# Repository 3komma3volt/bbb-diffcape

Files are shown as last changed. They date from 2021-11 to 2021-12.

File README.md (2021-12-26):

# bbb-diffcape

A simple Beaglebone black cape for controlling LED pixels with differential signals

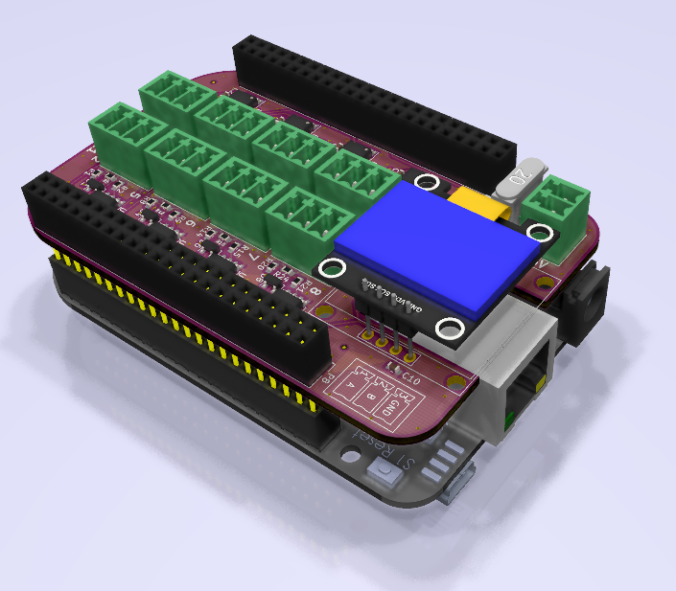
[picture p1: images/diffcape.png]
bbbdiffcape


# Usage
It consists of a simple cape with 8 diffential (RS422) outputs to control pixel strings (e.g. with WS2812B LEDs) over long distances. 
The project includes a receiver board to generate single-ended data for the pixels
It is compatible with [FPP Falcon Player](https://github.com/FalconChristmas/fpp) 
The manufacturing files include LCSC component numbers for direct ordering at [JLCPCB](https://jlcpcb.com)
Only the direct-solder fuse, the headers and the screw terminals have to be soldered manually, if ordered at JLCPCB.

> The boards have very simple designs. 2 layer, no impedance matching, only a bit ESD protection, no supply protection!

## Sending Cape

The folder **bbb-diffcape** contains the [KICAD](https://www.kicad.org) schematic, board and Gerber files. 

> Be aware that the Gerbers and board file are not consistent! In the  Gerbers, the screw terminals are a bit too narrow to each other. It works, but the plugged in connectors have to be bend a bit. The KICAD board is already corrected in R2.

 -  A 0.96" I2C OLED TFT can be mounted, which is supported by FPP to get some status information.
 - 5V connector supplies the Beaglebone and the Diffcape
 - Copy the BBB-Diff.json to the */opt/fpp/capes/bbb/strings* folder for correct configuration within FPP

# bbb-diffcape

A simple Beaglebone black cape for controlling LED pixels with differential signals

bbbdiffcape

# Usage
It consists of a simple cape with 8 diffential (RS422) outputs to control pixel strings (e.g. with WS2812B LEDs) over long distances. 
The project includes a receiver board to generate single-ended data for the pixels
It is compatible with [FPP Falcon Player](https://github.com/FalconChristmas/fpp) 
The manufacturing files include LCSC component numbers for direct ordering at [JLCPCB](https://jlcpcb.com)
Only the direct-solder fuse, the headers and the screw terminals have to be soldered manually, if ordered at JLCPCB.

> The boards have very simple designs. 2 layer, no impedance matching, only a bit ESD protection, no supply protection!

## Sending Cape

The folder **bbb-diffcape** contains the [KICAD](https://www.kicad.org) schematic, board and Gerber files. 

> Be aware that the Gerbers and board file are not consistent! In the  Gerbers, the screw terminals are a bit too narrow to each other. It works, but the plugged in connectors have to be bend a bit. The KICAD board is already corrected in R2.

 -  A 0.96" I2C OLED TFT can be mounted, which is supported by FPP to get some status information.
 - 5V connector supplies the Beaglebone and the Diffcape
 - Copy the BBB-Diff.json to the */opt/fpp/capes/bbb/strings* folder for correct configuration within FPP

> This board is tested and fully functional on all channels!

## Receiver

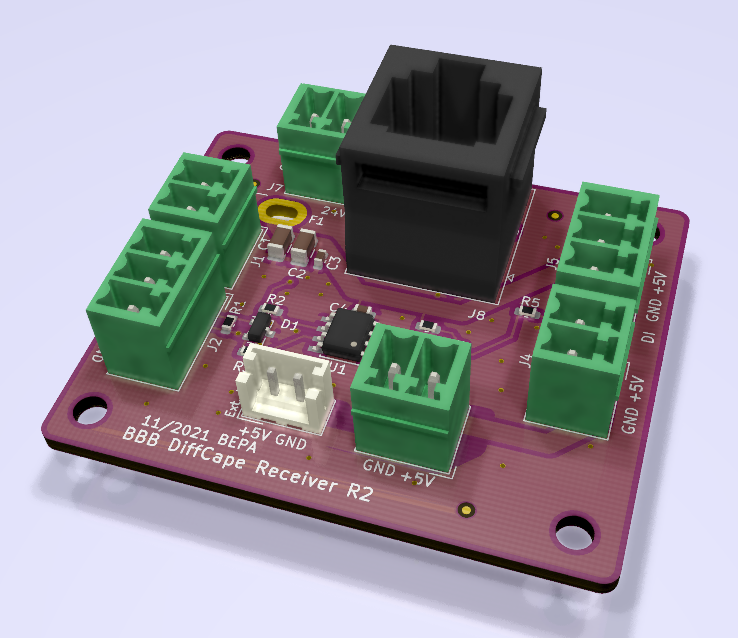
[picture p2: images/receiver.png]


The receiver is designed to support two supply variants

 - Supply with 5V: Just connect power and data as in the picture and the pixel string
 - Supply with 24V via RJ45: For easier cableing, a RJ45 connector for data and power. So there has to be a 24V power supply on the transmission side which powers the system. On the receiver side, a DC/DC converter is needed to power down to 5V. 
 - Excellent for per-prop-use. So one receiver per prop can be used with simple RJ45 cabelling (22AWG) with ~25W supply @ 10m without a big voltage drop
 - Folder "mechanical" contains a FreeCAD file for a simple hotglue mount
 
Because there is no voltage regulator, the receiver is not suited for use with 12V pixels without modifications!

> This board is tested and fully functional!

## ReceiverTransmitter

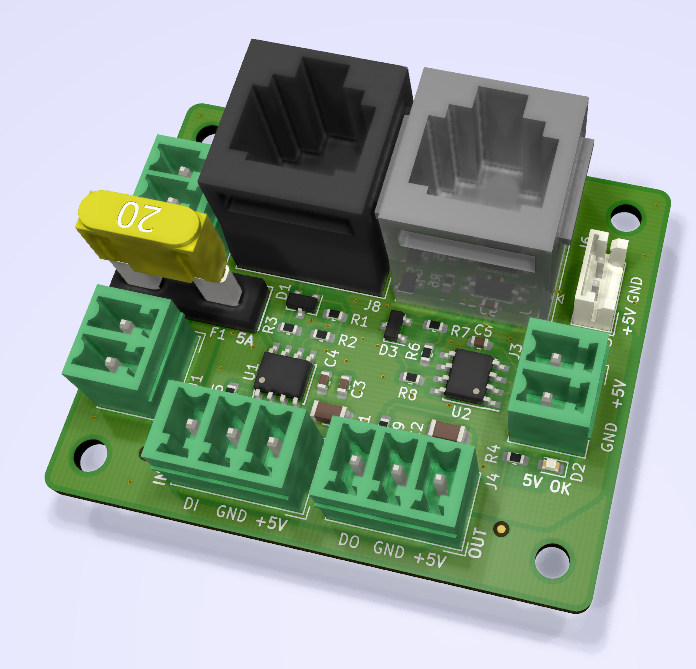
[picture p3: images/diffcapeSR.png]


Receiver with integrated transmitter. With this PCB, you can go back from the last pixel's output to the board and regenerate differential data. It also forwards the 24V power via the RJ45 connector.

> This board is tested and fully functional!

## Distributor

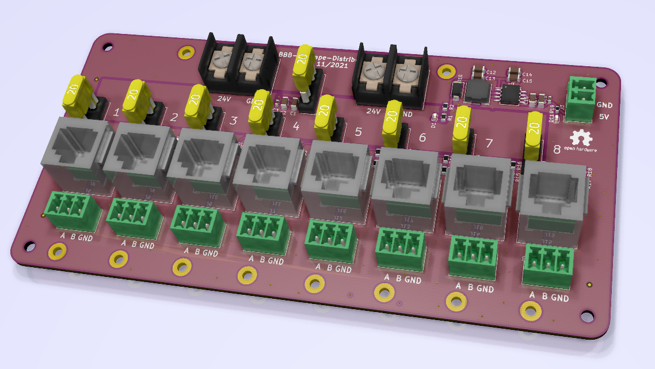
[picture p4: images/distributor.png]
bbbdistributor


With the distributor power and data can be transfered with standard patch cords. A 3A 5V DC/DC converter is used to supply the beaglebone black

> This board is untested!

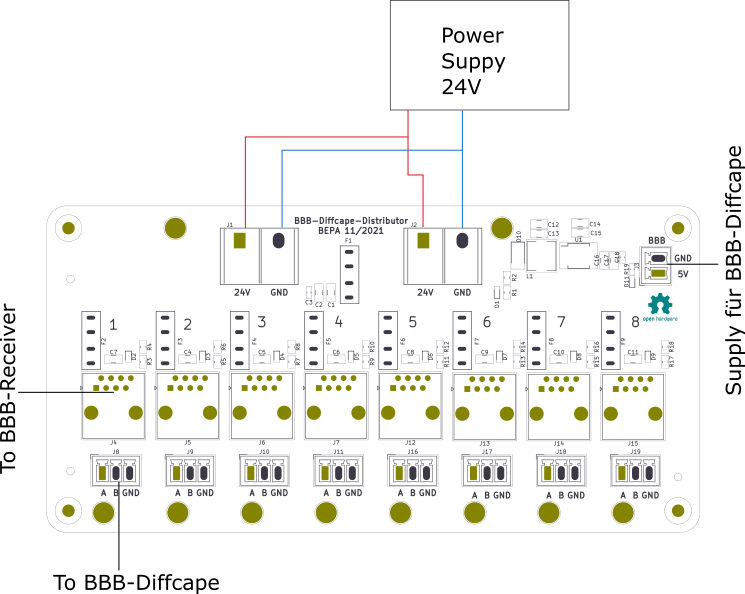
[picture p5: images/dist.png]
bbbdistributorconn


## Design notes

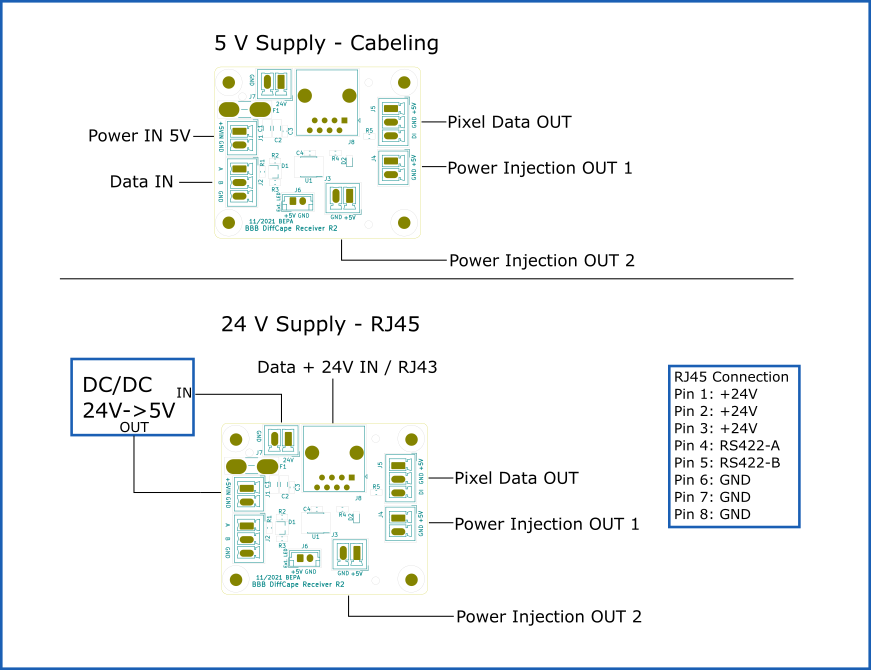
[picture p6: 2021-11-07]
images/bbb-diffcape-receiver-brd.png

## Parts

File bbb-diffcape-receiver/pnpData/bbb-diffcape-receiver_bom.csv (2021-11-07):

Comment | Designator | Footprint | LCSC
100u | C1,C2 | Capacitor_SMD:C_1206_3216Metric | C15008
100n | C3,C4 | Capacitor_SMD:C_0603_1608Metric | C14663
PSM712 | D1 | Package_TO_SOT_SMD:SOT-23 | C32677
LED | D2 | LED_SMD:LED_0603_1608Metric | C72038
5A | F1 | Fuse:Fuse_Blade_Mini_directSolder
Fiducial | FID1,FID2,FID3 | Fiducial:Fiducial_0.75mm_Mask1.5mm
MountingHole | H1,H2,H3,H4 | MountingHole:MountingHole_3.2mm_M3
Screw_Terminal_01x03 | J2,J5 | Connector_Phoenix_MC:PhoenixContact_MCV_1,5_3-G-3.5_1x03_P3.50mm_Vertical
Screw_Terminal_01x02 | J1,J3,J4,J7 | Connector_Phoenix_MC:PhoenixContact_MCV_1,5_2-G-3.5_1x02_P3.50mm_Vertical
Conn_01x02_Male | J6 | Connector_JST:JST_EH_B2B-EH-A_1x02_P2.50mm_Vertical
RJ45 | J8 | Connector_RJ:RJ45_OST_PJ012-8P8CX_Vertical
120 | R1 | Resistor_SMD:R_0603_1608Metric | C22787
10 | R2,R3,R5 | Resistor_SMD:R_0603_1608Metric | C22859
470 | R4 | Resistor_SMD:R_0603_1608Metric | C23182
SP3485EN | U1 | Package_SO:SOIC-8_3.9x4.9mm_P1.27mm

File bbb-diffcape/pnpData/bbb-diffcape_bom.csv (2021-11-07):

Comment | Designator | Footprint | LCSC
SSD1306 | Brd1 | oled:128x64OLED
100n | C1,C2,C3,C6,C7,C8,C9,C10,C11,C12 | Capacitor_SMD:C_0603_1608Metric | C14663
100u | C4,C5 | Capacitor_SMD:C_1206_3216Metric | C15008
PSM712 | D1,D2,D4,D5,D6,D7,D8,D9 | Package_TO_SOT_SMD:SOT-23 | C32677
LED | D3 | LED_SMD:LED_0603_1608Metric | C72038
2A | F1 | Fuse:Fuse_Blade_Mini_directSolder
Fiducial | FID1,FID2,FID3 | Fiducial:Fiducial_0.5mm_Mask1mm
Screw_Terminal_01x02 | J1 | Connector_Phoenix_MC:PhoenixContact_MCV_1,5_2-G-3.5_1x02_P3.50mm_Vertical
Screw_Terminal_01x03 | J2,J3,J4,J5,J6,J7,J8,J9 | Connector_Phoenix_MC:PhoenixContact_MCV_1,5_3-G-3.5_1x03_P3.50mm_Vertical
BeagleBone_Black_Header | P8,P9 | Socket_BeagleBone_Black:Socket_BeagleBone_Black
10 | R1,R2,R3,R4,R8,R9,R10,R11,R14,R15,R16,R17,R20,R21,R22,R23 | Resistor_SMD:R_0603_1608Metric | C22859
120 | R5,R6,R12,R13,R18,R19,R24,R25 | Resistor_SMD:R_0603_1608Metric | C22787
470 | R7 | Resistor_SMD:R_0603_1608Metric | C23182
SP3485EN | U1,U2,U3,U4,U5,U6,U7,U8 | Package_SO:SOIC-8_3.9x4.9mm_P1.27mm | C8963

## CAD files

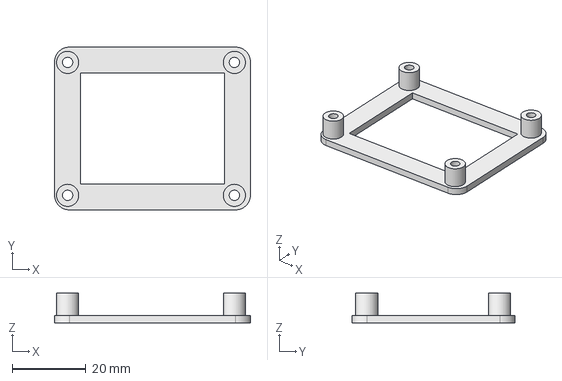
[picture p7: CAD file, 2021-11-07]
mechanical/receiverholdermount.FCStd
53.0 x 44.0 x 8.00 mm

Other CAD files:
mechanical/receiverholdermount.stl

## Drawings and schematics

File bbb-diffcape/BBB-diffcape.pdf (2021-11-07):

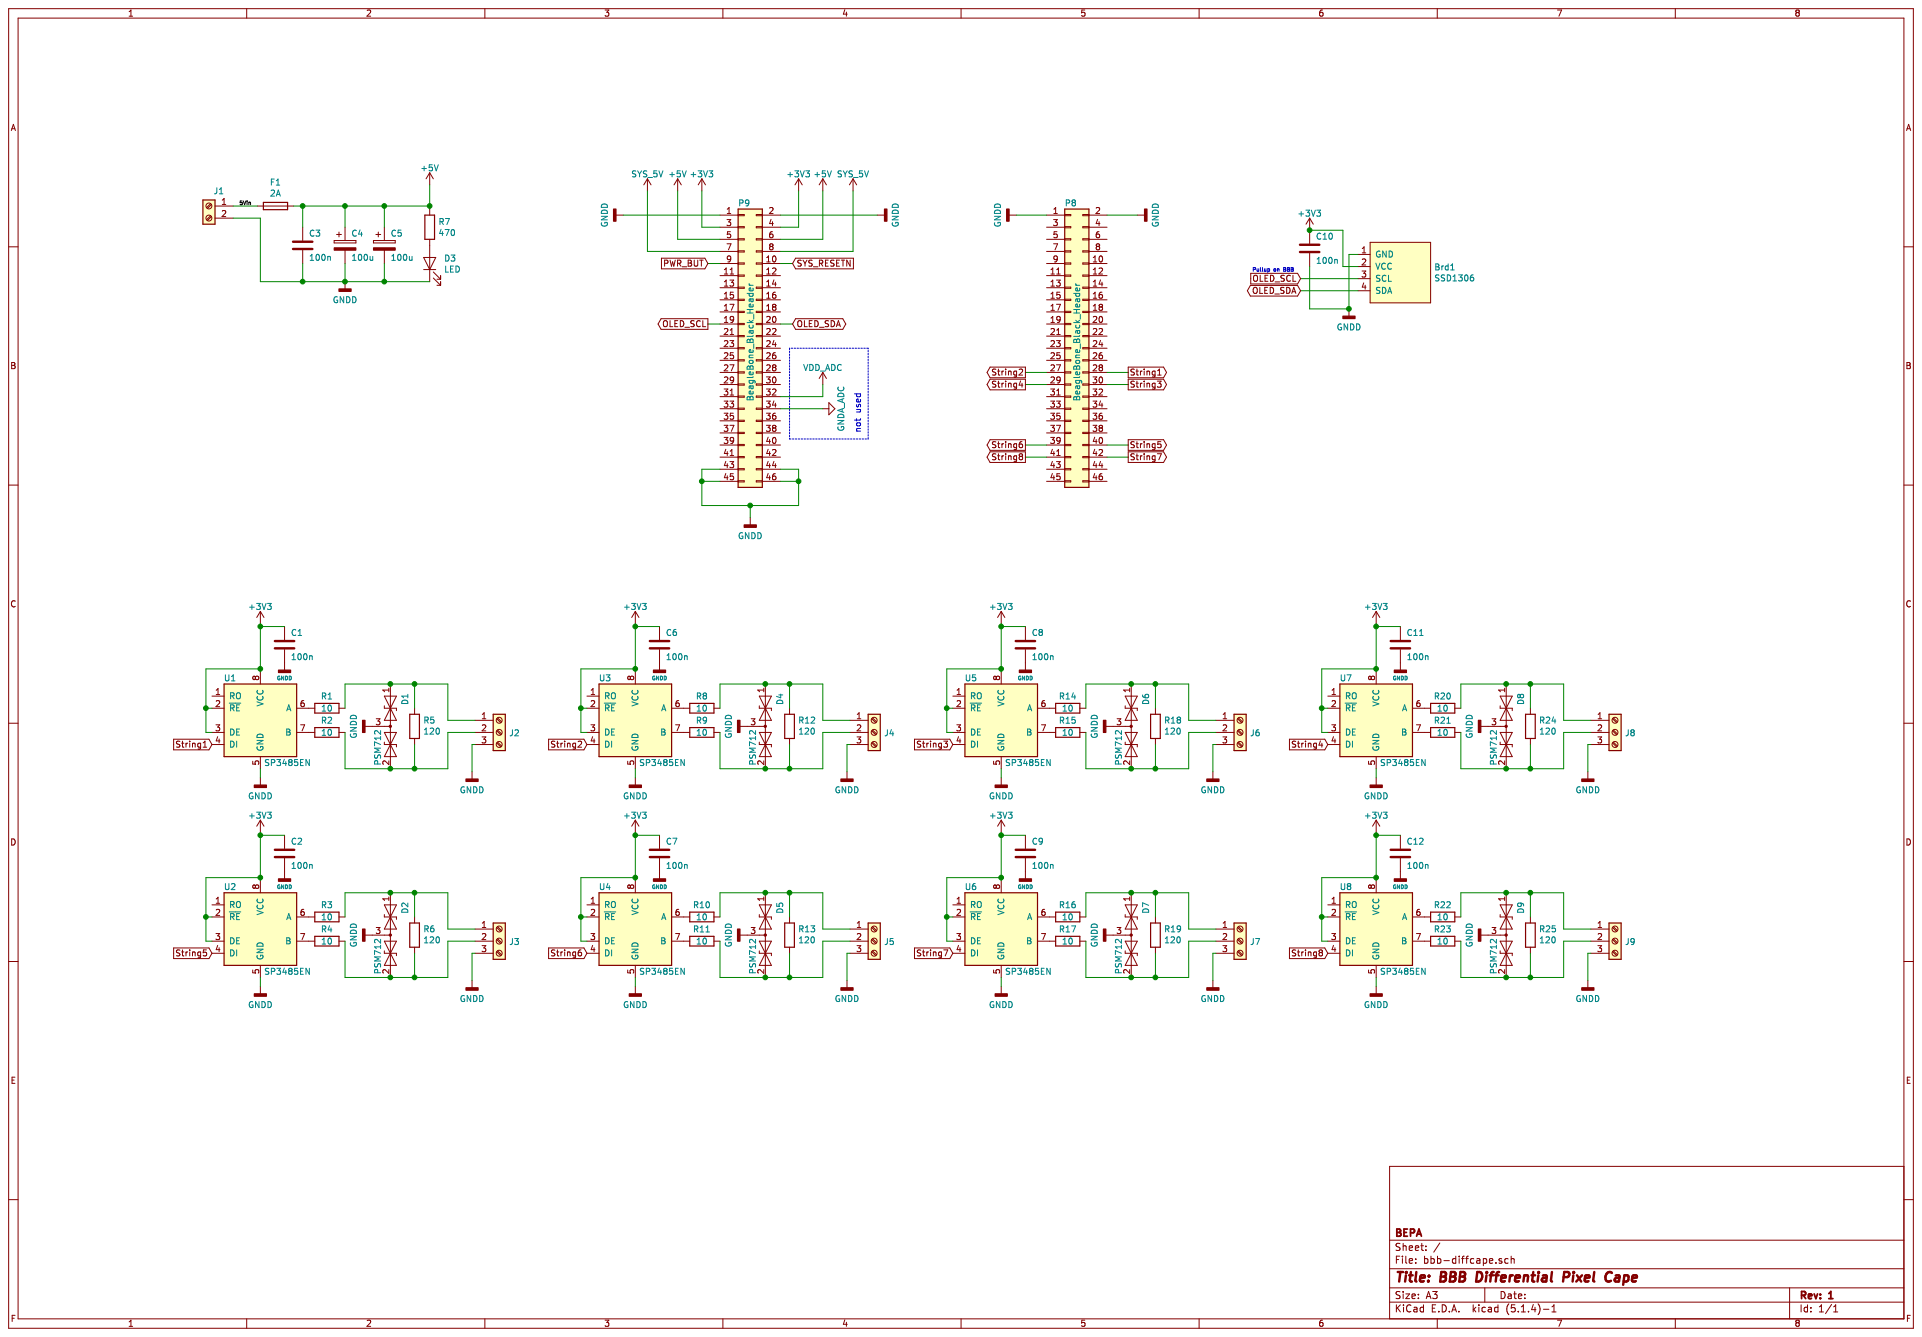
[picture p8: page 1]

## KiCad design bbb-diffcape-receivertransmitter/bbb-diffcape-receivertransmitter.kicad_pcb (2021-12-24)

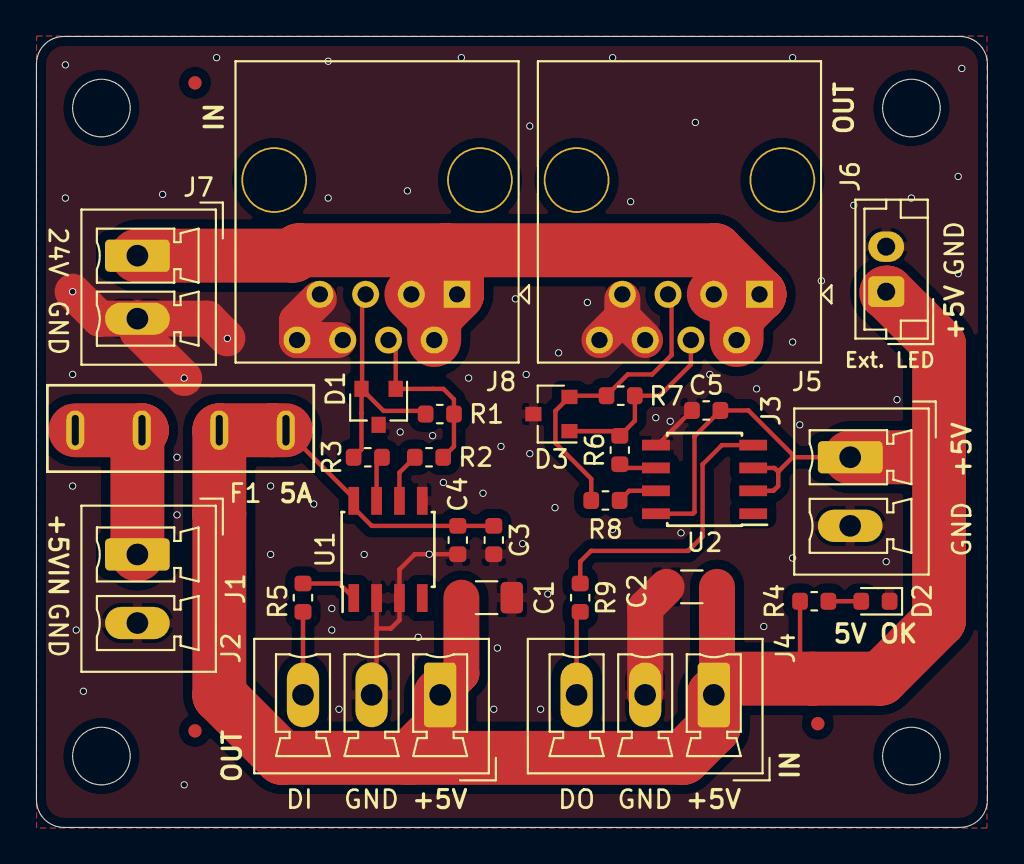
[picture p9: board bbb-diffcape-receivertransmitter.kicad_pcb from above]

Board: 2 copper layers, 52.8 x 43.9 mm, 35 parts (0 on the bottom side), 17 nets.

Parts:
C1, C2: 100u; C_1206_3216Metric
C3, C4, C5: 100n; C_0603_1608Metric
D1, D3: PSM712; SOT-23
D2: LED; LED_0603_1608Metric
F1: 5A; TLZWLA-Minifuse
FID1, FID2, FID3: Fiducial; Fiducial_0.75mm_Mask1.5mm
H1, H2, H3, H4: MountingHole; MountingHole_3.2mm_M3
J1, J3: Screw_Terminal_01x02; PhoenixContact_MCV_1,5_2-G-3.81_1x02_P3.81mm_Vertical
J2, J4: Screw_Terminal_01x03; PhoenixContact_MCV_1,5_3-G-3.81_1x03_P3.81mm_Vertical
J5, J8: RJ45; RJ45_OST_PJ012-8P8CX_Vertical
J6: Conn_01x02_Male; JST_EH_B2B-EH-A_1x02_P2.50mm_Vertical
J7: Screw_Terminal_01x02; PhoenixContact_MCV_1,5_2-G-3.5_1x02_P3.50mm_Vertical
R1, R7: 120; R_0603_1608Metric
R2, R3, R5, R6, R8, R9: 10; R_0603_1608Metric
R4: 470; R_0603_1608Metric
U1, U2: SP3485EN; SOIC-8_3.9x4.9mm_P1.27mm

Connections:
+5V: C1.1, C2.1, C3.1, C4.1, C5.1, F1.1, J2.1, J3.1, J4.1, J6.1, R4.2, U1.8, U2.2, U2.3, U2.8
+24V: J5.1, J5.2, J5.3, J7.1, J8.1, J8.2, J8.3
/DataIn: J4.3, R9.2
/PW_In: F1.2, J1.1
/RS422_A: D1.1, J8.4, R1.1, R2.1
/RS422_A_Out: D3.1, J5.4, R6.1, R7.1
/RS422_B: D1.2, J8.5, R1.2, R3.1
/RS422_B_Out: D3.2, J5.5, R7.2, R8.1
GNDD: C1.2, C2.2, C3.2, C4.2, C5.2, D1.3, D2.1, D3.3, J1.2, J2.2, J3.2, J4.2, J5.6, J5.7, J5.8, J6.2, J7.2, J8.6, J8.7, J8.8, U1.2, U1.3, U1.5, U2.5
unnamed: D2.2, R4.1
unnamed: J2.3, R5.2
unnamed: R2.2, U1.6
unnamed: R3.2, U1.7
unnamed: R5.1, U1.1
unnamed: R6.2, U2.6
unnamed: R8.2, U2.7
unnamed: R9.1, U2.4

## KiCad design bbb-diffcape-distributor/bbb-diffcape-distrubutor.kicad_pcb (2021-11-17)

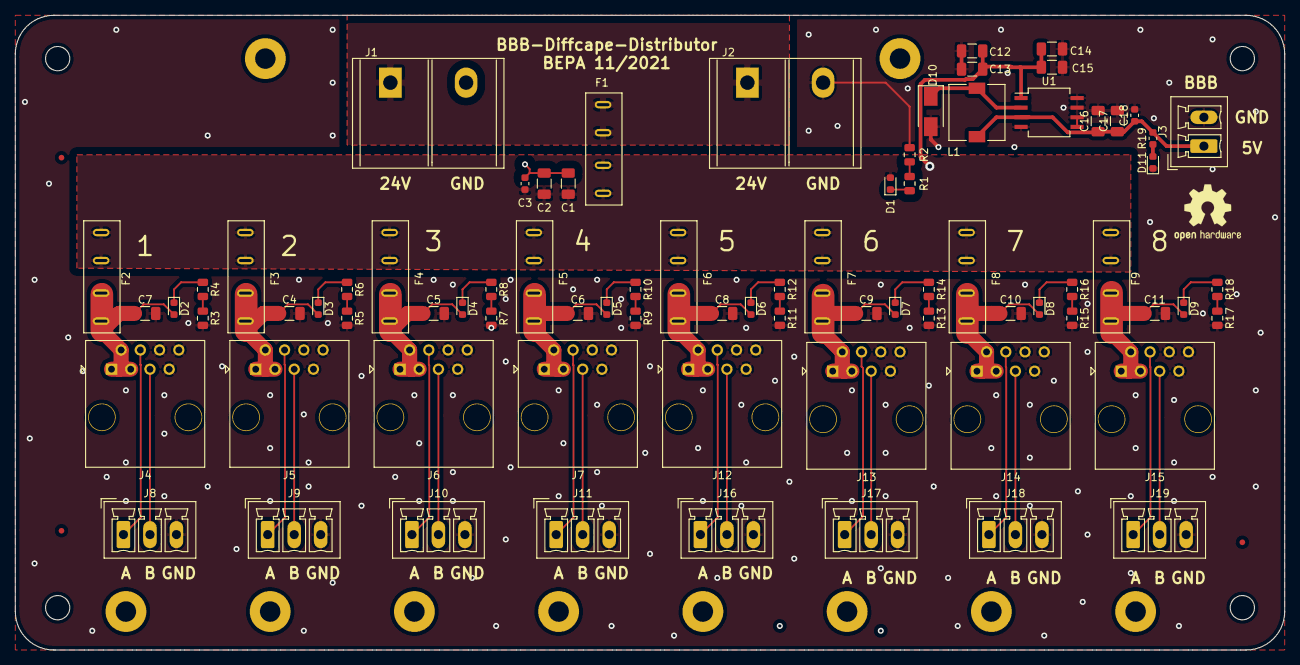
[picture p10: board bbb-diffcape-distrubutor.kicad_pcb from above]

Board: 2 copper layers, 167.6 x 83.8 mm, 85 parts (0 on the bottom side), 48 nets.

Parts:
C1, C2, C4, C5, C6, C7, C8, C9, C10, C11, C12, C13, C14, C15, C16, C17: 100u; C_1206_3216Metric
C3, C18: 100n; C_0603_1608Metric
D1, D2, D3, D4, D5, D6, D7, D8, D9, D11: LED; LED_0603_1608Metric
D10: SS54; D_SMA
F1: 20A; TLZWLA-Minifuse
F2, F3, F4, F5, F6, F7, F8, F9: 2A; TLZWLA-Minifuse
FID1, FID2, FID3: Fiducial; Fiducial_0.75mm_Mask1.5mm
H1, H2, H3, H4: MountingHole; MountingHole_3.2mm_M3
J1, J2: Screw_Terminal_01x02; KF1000-2P
J3: Screw_Terminal_01x02; PhoenixContact_MCV_1,5_2-G-3.81_1x02_P3.81mm_Vertical
J4, J5, J6, J7, J12, J13, J14, J15: RJ45; RJ45_OST_PJ012-8P8CX_Vertical
J8, J9, J10, J11, J16, J17, J18, J19: Screw_Terminal_01x03; PhoenixContact_MCV_1,5_3-G-3.5_1x03_P3.50mm_Vertical
L1: 68uH; L_7.3x7.3_H3.5
R1, R2, R3, R4, R5, R6, R7, R8, R9, R10, R11, R12, R13, R14, R15, R16, R17, R18: 1k2; R_0805_2012Metric
R19: 470; R_0603_1608Metric
U1: XL1509-5.0E1; SO-8_5.3x6.2mm_P1.27mm

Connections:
+5V: C16.1, C17.1, C18.1, J3.1, L1.2, R19.2, U1.3
+24V: C1.1, C2.1, C3.1, C12.1, C13.1, C14.1, C15.1, D1.2, F1.1, F2.2, F3.2, F4.2, F5.2, F6.2, F7.2, F8.2, F9.2, U1.1
/PW_In: F1.2, J1.1, J2.1
GNDD: C1.2, C2.2, C3.2, C4.2, C5.2, C6.2, C7.2, C8.2, C9.2, C10.2, C11.2, C12.2, C13.2, C14.2, C15.2, C16.2, C17.2, C18.2, D10.2, D11.1, J1.2, J2.2, J3.2, J4.6, J4.7, J4.8, J5.6, J5.7, J5.8, J6.6, J6.7, J6.8, J7.6, J7.7, J7.8, J8.3, J9.3, J10.3, J11.3, J12.6, J12.7, J12.8, J13.6, J13.7, J13.8, J14.6, J14.7, J14.8, J15.6, J15.7, J15.8, J16.3, J17.3, J18.3, J19.3, R2.2, R3.2, R5.2, R7.2, R9.2, R11.2, R13.2, R15.2, R17.2, U1.4, U1.5, U1.6, U1.7, U1.8
unnamed: C4.1, D3.2, F3.1, J5.1, J5.2, J5.3
unnamed: C5.1, D4.2, F4.1, J6.1, J6.2, J6.3
unnamed: C6.1, D5.2, F5.1, J7.1, J7.2, J7.3
unnamed: C7.1, D2.2, F2.1, J4.1, J4.2, J4.3
unnamed: C8.1, D6.2, F6.1, J12.1, J12.2, J12.3
unnamed: C9.1, D7.2, F7.1, J13.1, J13.2, J13.3
unnamed: C10.1, D8.2, F8.1, J14.1, J14.2, J14.3
unnamed: C11.1, D9.2, F9.1, J15.1, J15.2, J15.3
unnamed: D1.1, R1.1
unnamed: D2.1, R4.1
unnamed: D3.1, R6.1
unnamed: D4.1, R8.1
unnamed: D5.1, R10.1
unnamed: D6.1, R12.1
unnamed: D7.1, R14.1
unnamed: D8.1, R16.1
unnamed: D9.1, R18.1
unnamed: D10.1, L1.1, U1.2
unnamed: D11.2, R19.1
unnamed: J4.4, J8.1
unnamed: J4.5, J8.2
unnamed: J5.4, J9.1
unnamed: J5.5, J9.2
unnamed: J6.4, J10.1
unnamed: J6.5, J10.2
unnamed: J7.4, J11.1
unnamed: J7.5, J11.2
unnamed: J12.4, J16.1
unnamed: J12.5, J16.2
unnamed: J13.4, J17.1
unnamed: J13.5, J17.2
unnamed: J14.4, J18.1
unnamed: J14.5, J18.2
unnamed: J15.4, J19.1
unnamed: J15.5, J19.2
unnamed: R1.2, R2.1
unnamed: R3.1, R4.2
unnamed: R5.1, R6.2
unnamed: R7.1, R8.2
unnamed: R9.1, R10.2
unnamed: R11.1, R12.2
unnamed: R13.1, R14.2
unnamed: R15.1, R16.2
unnamed: R17.1, R18.2

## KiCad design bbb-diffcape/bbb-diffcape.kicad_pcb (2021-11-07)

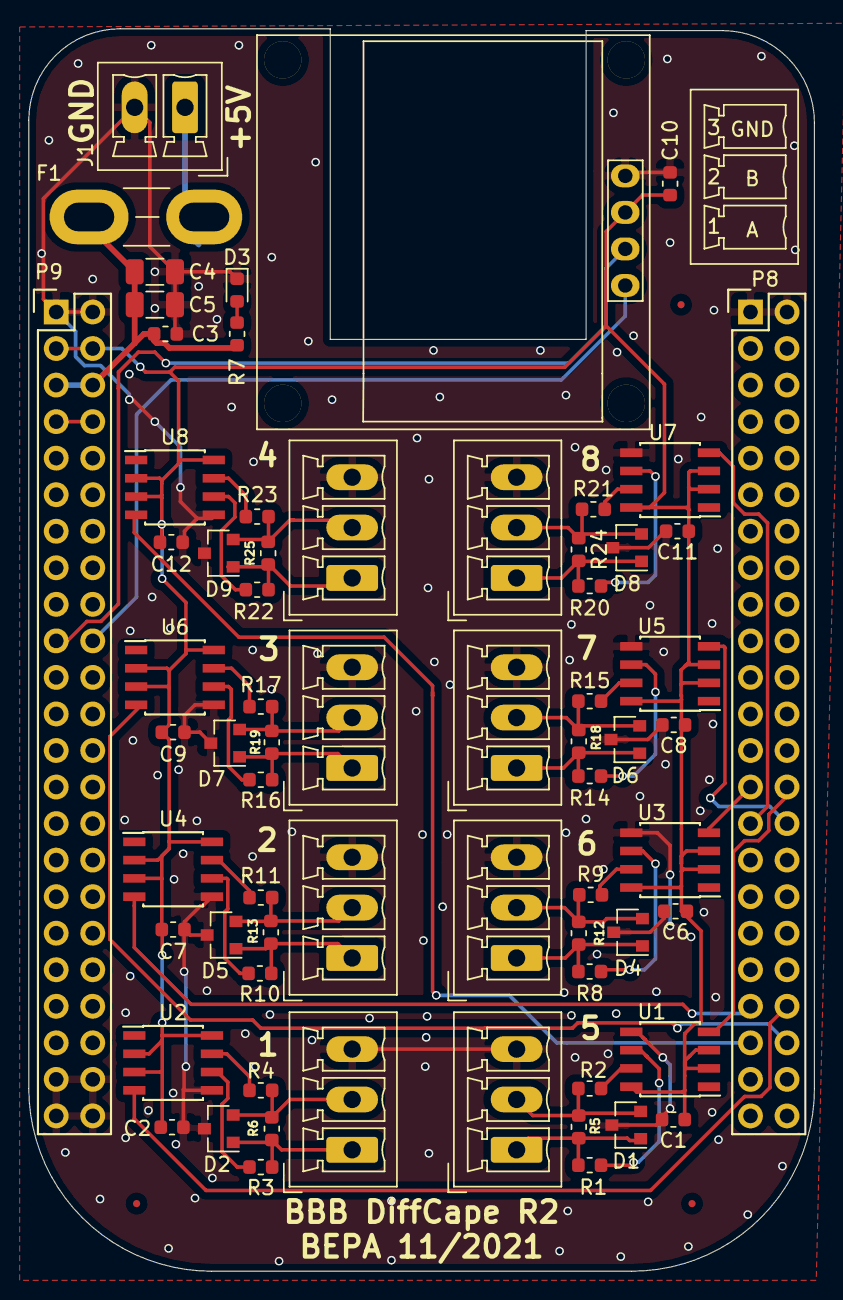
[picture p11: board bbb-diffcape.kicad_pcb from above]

Board: 2 copper layers, 54.6 x 86.4 mm, 70 parts (0 on the bottom side), 48 nets.

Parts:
Brd1: SSD1306; 128x64OLED
C1, C2, C3, C6, C7, C8, C9, C10, C11, C12: 100n; C_0603_1608Metric
C4, C5: 100u; C_1206_3216Metric
D1, D2, D4, D5, D6, D7, D8, D9: PSM712; SOT-23
D3: LED; LED_0603_1608Metric
F1: 2A; Fuse_Blade_Mini_directSolder
FID1, FID2, FID3: Fiducial; Fiducial_0.5mm_Mask1mm
J1: Screw_Terminal_01x02; PhoenixContact_MCV_1,5_2-G-3.5_1x02_P3.50mm_Vertical
J2, J3, J4, J5, J6, J7, J8, J9: Screw_Terminal_01x03; PhoenixContact_MCV_1,5_3-G-3.5_1x03_P3.50mm_Vertical
P8, P9: BeagleBone_Black_Header; Socket_BeagleBone_Black
R1, R2, R3, R4, R8, R9, R10, R11, R14, R15, R16, R17, R20, R21, R22, R23: 10; R_0603_1608Metric
R5, R6, R12, R13, R18, R19, R24, R25: 120; R_0603_1608Metric
R7: 470; R_0603_1608Metric
U1, U2, U3, U4, U5, U6, U7, U8: SP3485EN; SOIC-8_3.9x4.9mm_P1.27mm

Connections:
+3V3: Brd1.2, C1.1, C2.1, C6.1, C7.1, C8.1, C9.1, C10.1, C11.1, C12.1, P9.3, P9.4, U1.2, U1.3, U1.8, U2.2, U2.3, U2.8, U3.2, U3.3, U3.8, U4.2, U4.3, U4.8, U5.2, U5.3, U5.8, U6.2, U6.3, U6.8, U7.2, U7.3, U7.8, U8.2, U8.3, U8.8
+5V: C3.1, C4.1, C5.1, F1.1, P9.5, P9.6, R7.1
/5Vin: F1.2, J1.1
GNDD: Brd1.1, C1.2, C2.2, C3.2, C4.2, C5.2, C6.2, C7.2, C8.2, C9.2, C10.2, C11.2, C12.2, D1.3, D2.3, D3.1, D4.3, D5.3, D6.3, D7.3, D8.3, D9.3, J1.2, J2.3, J3.3, J4.3, J5.3, J6.3, J7.3, J8.3, J9.3, P8.1, P8.2, P9.1, P9.2, P9.43, P9.44, P9.45, P9.46, U1.5, U2.5, U3.5, U4.5, U5.5, U6.5, U7.5, U8.5
unnamed: D1.1, J2.1, R1.1, R5.2
unnamed: D1.2, J2.2, R2.1, R5.1
unnamed: D2.1, J3.1, R3.1, R6.2
unnamed: D2.2, J3.2, R4.1, R6.1
unnamed: D3.2, R7.2
unnamed: D4.1, J4.1, R8.1, R12.2
unnamed: D4.2, J4.2, R9.1, R12.1
unnamed: D5.1, J5.1, R10.1, R13.2
unnamed: D5.2, J5.2, R11.1, R13.1
unnamed: D6.1, J6.1, R14.1, R18.2
unnamed: D6.2, J6.2, R15.1, R18.1
unnamed: D7.1, J7.1, R16.1, R19.2
unnamed: D7.2, J7.2, R17.1, R19.1
unnamed: D8.1, J8.1, R20.1, R24.2
unnamed: D8.2, J8.2, R21.1, R24.1
unnamed: D9.1, J9.1, R22.1, R25.2
unnamed: D9.2, J9.2, R23.1, R25.1
unnamed: R1.2, U1.6
unnamed: R2.2, U1.7
unnamed: R3.2, U2.6
unnamed: R4.2, U2.7
unnamed: R8.2, U3.6
unnamed: R9.2, U3.7
unnamed: R10.2, U4.6
unnamed: R11.2, U4.7
unnamed: R14.2, U5.6
unnamed: R15.2, U5.7
unnamed: R16.2, U6.6
unnamed: R17.2, U6.7
unnamed: R20.2, U7.6
unnamed: R21.2, U7.7
unnamed: R22.2, U8.6
unnamed: R23.2, U8.7
OLED_SCL: Brd1.3, P9.19
OLED_SDA: Brd1.4, P9.20
SYS_5V: P9.7, P9.8
String1: P8.28, U1.4
String2: P8.27, U3.4
String3: P8.30, U5.4
String4: P8.29, U7.4
String5: P8.40, U2.4
String6: P8.39, U4.4
String7: P8.42, U6.4
String8: P8.41, U8.4

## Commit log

2021-11-07 Add files via upload
    Initial commit
    [bbb-diffcape-B_Cu.gbr, bbb-diffcape-B_Mask.gbr, bbb-diffcape-B_Paste.gbr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]
2021-11-17 Added distributor
    Added schematic and board for distributor
    [bbb-diffcape-distrubutor.kicad_pcb, bbb-diffcape-distrubutor.sch]
2021-11-17 Corrected folders, added some documentation in readme
    [bbb-diffcape-distrubutor.kicad_pcb, bbb-diffcape-distrubutor.sch]
2021-12-10 Added new receiver/transmitter PCB
    [bbb-diffcape-receivertransmitter.kicad_pcb, bbb-diffcape-receivertransmitter.sch]
2021-12-24 Corrected Input and Output labeling on silkscreen
    [bbb-diffcape-receivertransmitter.kicad_pcb]
